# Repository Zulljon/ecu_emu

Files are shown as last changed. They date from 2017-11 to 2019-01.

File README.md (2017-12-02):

# ECU emulator v3.1a
PCB part of project (source codes unavailable!)

## Scheme
scheme_svg
scheme_pdf

## PCB
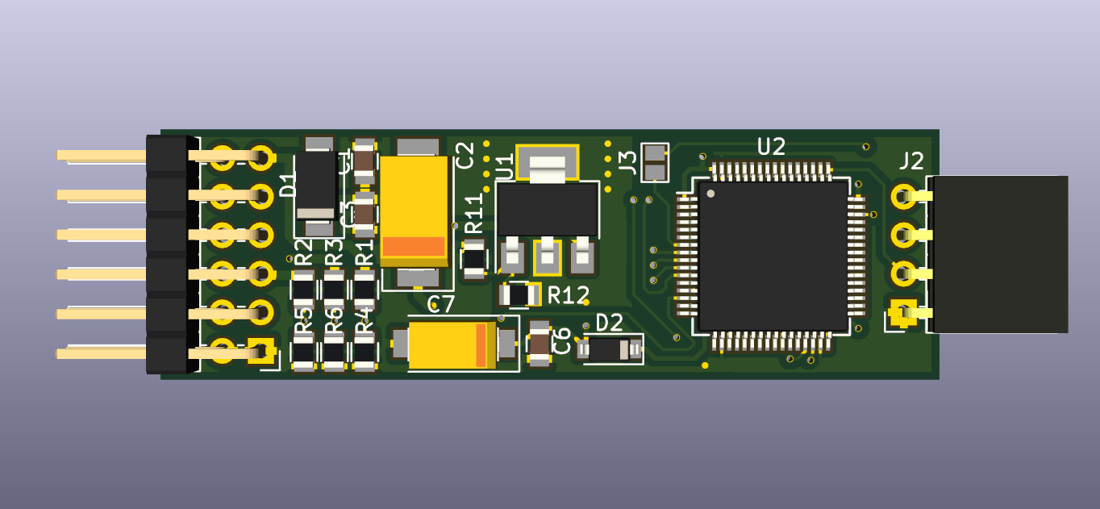
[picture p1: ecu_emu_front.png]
FRONT_side_png

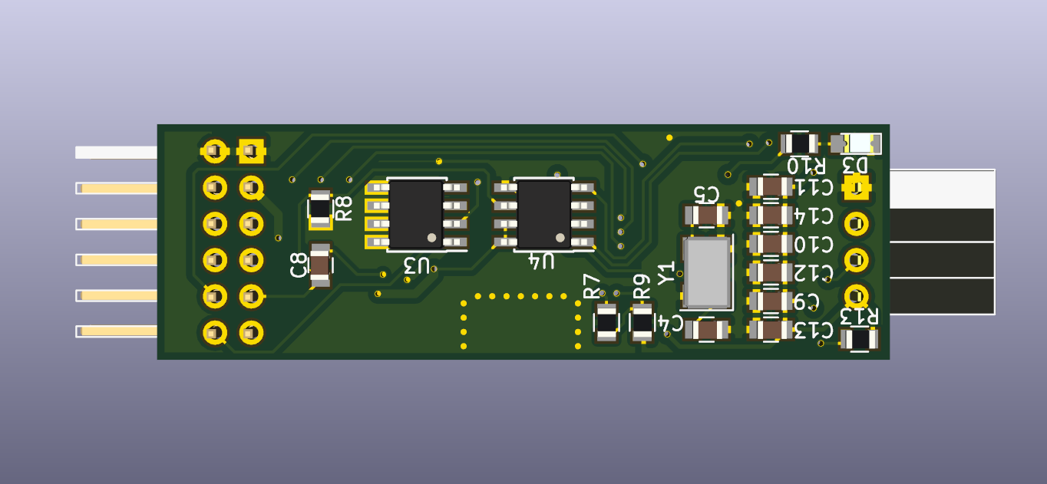
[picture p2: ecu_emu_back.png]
BACK_side_png

### With FreeCAD PCB mod
pcb_mod
### With FreeCAD KiCAD StepUp mod
stepup_mod

## Tools
- KiCAD v4.0.7
- FreeCAD v0.15

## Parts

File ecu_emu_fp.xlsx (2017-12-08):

Source: | d:/zulljon/KiCAD/ecu_emu/ecu_emu.sch
Date: | 2017-12-07 18:20
Tool: | Eeschema 4.0.7
Generator: | C:/Program Files/KiCad/bin/scripting/plugins/bom_csv_grouped_by_value_with_fp.py
Component Count: | 34
Ref | Qnty | Value | Cmp name | Footprint | Description | Vendor
C1, | 1 | 10nF | C | Capacitors_SMD:C_0805 | Unpolarized capacitor
C2, | 1 | 220uF x 30V | CP | Capacitors_Tantalum_SMD:CP_Tantalum_Case-X_EIA-7343-43_Wave | Polarised capacitor
C3, C10, C11, C12, C13, C14, | 6 | 100nF | C | Capacitors_SMD:C_0805 | Unpolarized capacitor
C4, C5, | 2 | 16pF | C | Capacitors_SMD:C_0805 | Unpolarized capacitor
C6, | 1 | 10uF | C | Capacitors_SMD:C_0805 | Unpolarized capacitor
C7, | 1 | 47uF x 16V | CP | Capacitors_Tantalum_SMD:CP_Tantalum_Case-C_EIA-6032-28_Wave | Polarised capacitor
C8, | 1 | 1nF | C | Capacitors_SMD:C_0805 | Unpolarized capacitor
C9, | 1 | 4.7uF | C | Capacitors_SMD:C_0805 | Unpolarized capacitor
D1, | 1 | SS22A-SS210A-Galaxy | D_Schottky | Diodes_SMD:D_SMA | Schottky diode
D2, | 1 | PMLL4148L.115 | D | Diodes_SMD:D_SC-80 | Diode
D3, | 1 | LED | LED | LEDs:LED_0805 | LED generic
J1, | 1 | Conn_02x06_Odd_Even | Conn_02x06_Odd_Even | Pin_Headers:Pin_Header_Angled_2x06_Pitch2.54mm | Generic connector, double row, 02x06, odd/even pin numbering scheme (row 1 odd numbers, row 2 even numbers)
J2, | 1 | Conn_01x04_Male | Conn_01x04_Male | Socket_Strips:Socket_Strip_Angled_1x04_Pitch2.54mm | Generic connector, single row, 01x04
R1, R2, R3, | 3 | 9k | R | Resistors_SMD:R_0805 | Resistor
R4, R5, R6, | 3 | 2k2 | R | Resistors_SMD:R_0805 | Resistor
R7, R9, R8, R10, | 4 | 1k | R | Resistors_SMD:R_0805 | Resistor
U1, | 1 | LD1117S33TR_SOT223 | LD1117S33TR_SOT223 | TO_SOT_Packages_SMD:SOT-223-3_TabPin2 | 1A Low Dropout regulator, positive, 1.5V fixed output, SOT-223
U2, | 1 | STM32F105RBTx | STM32F105RBTx | Housings_QFP:LQFP-64_10x10mm_Pitch0.5mm | Core: ARM Cortex-M3 Package: LQFP64 Flash: 64KB Ram: 64KB Frequency: 72MHz Voltage: 2..3.6V IO-pins: 51
U3, | 1 | BSP742R | BSP742R | Housings_SOIC:SOIC-8_3.9x4.9mm_Pitch1.27mm | Smart High-Side Power Switch 34V DSO-8 BSP742R, Intelligent Power Switch High Side Switch, 0.4A, -10 ??? 16V, 8-Pin, PG-DSO-8-24
U4, | 1 | E-L9637D | E-L9637D | Housings_SOIC:SOIC-8_3.9x4.9mm_Pitch1.27mm | Monolithic Bus Driver ISO 9141 Interface
Y1, | 1 | Crystal KX-9A | Crystal_GND24 | Crystals:Crystal_SMD_5032-4pin_5.0x3.2mm | Four pin crystal (GND on pins 2 and 4), e.g. in SMD package

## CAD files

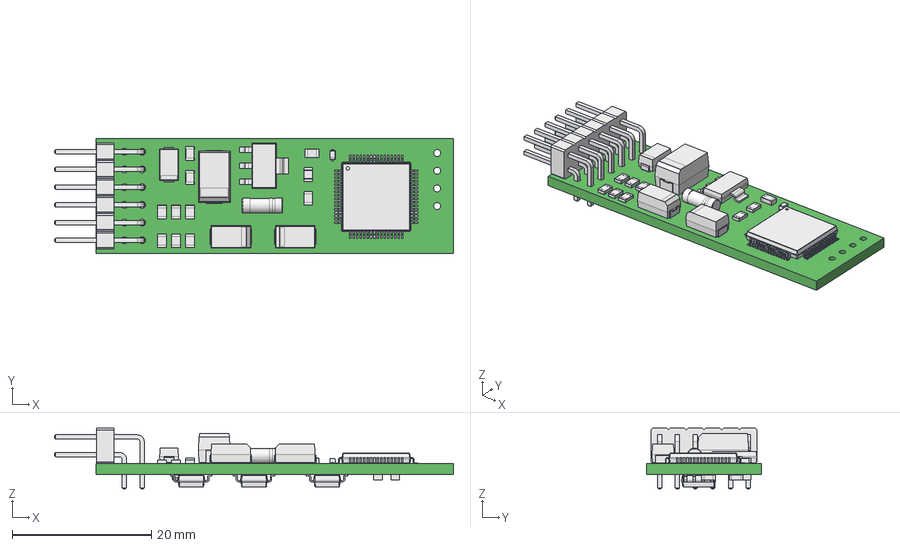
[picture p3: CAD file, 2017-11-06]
ecu_emu1.FCStd
57.3 x 16.5 x 8.72 mm
Pcb
C_0805_
C_0805_001
C_0805_002
C_0805_003
C_0805_004
C_0805_005
D_SMA_
D_SC_80_
Pin_Header_Angled_2x06_Pitch254mm_
SOIC-8_3.9x4.9mm_Pitch1.27mm_
R_0805_
R_0805_001
R_0805_002
R_0805_003
R_0805_004
R_0805_005
R_0805_006
R_0805_007
SOT_223_
LQFP-64_10x10mm_Pitch0.5mm_
SOIC-8_3.9x4.9mm_Pitch1.27mm_001
SOIC-8_3.9x4.9mm_Pitch1.27mm_002
CP_Tantalum_Case-X_EIA-7343-43_
CP_Tantalum_Case-C_EIA-6032-28_
CP_Tantalum_Case-C_EIA-6032-28_001
D_MELF_Standard_
R_0805_008

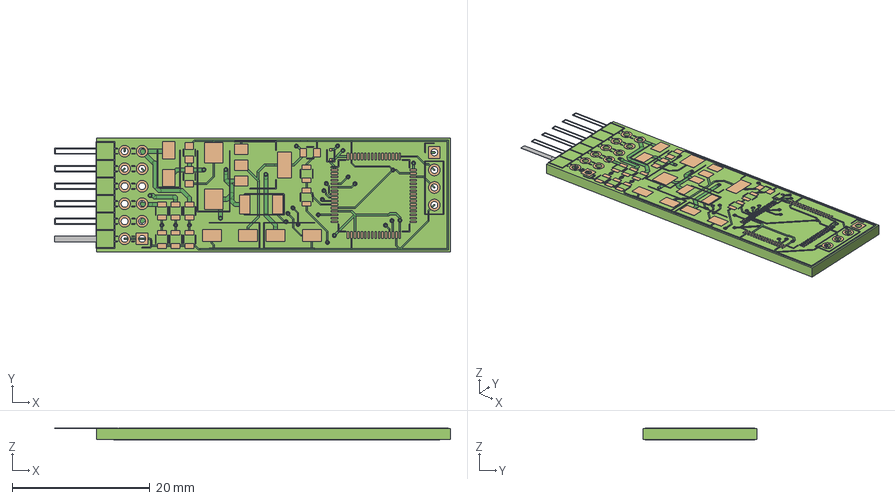
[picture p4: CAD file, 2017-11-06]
ecu_emu2.FCStd
57.4 x 16.5 x 1.67 mm
Board
F_Cu_0
bPad_107
tPad_108
B_Cu_31
B_SilkS_36
F_SilkS_37

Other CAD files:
ecu_emu1.stl
ecu_emu2.stl

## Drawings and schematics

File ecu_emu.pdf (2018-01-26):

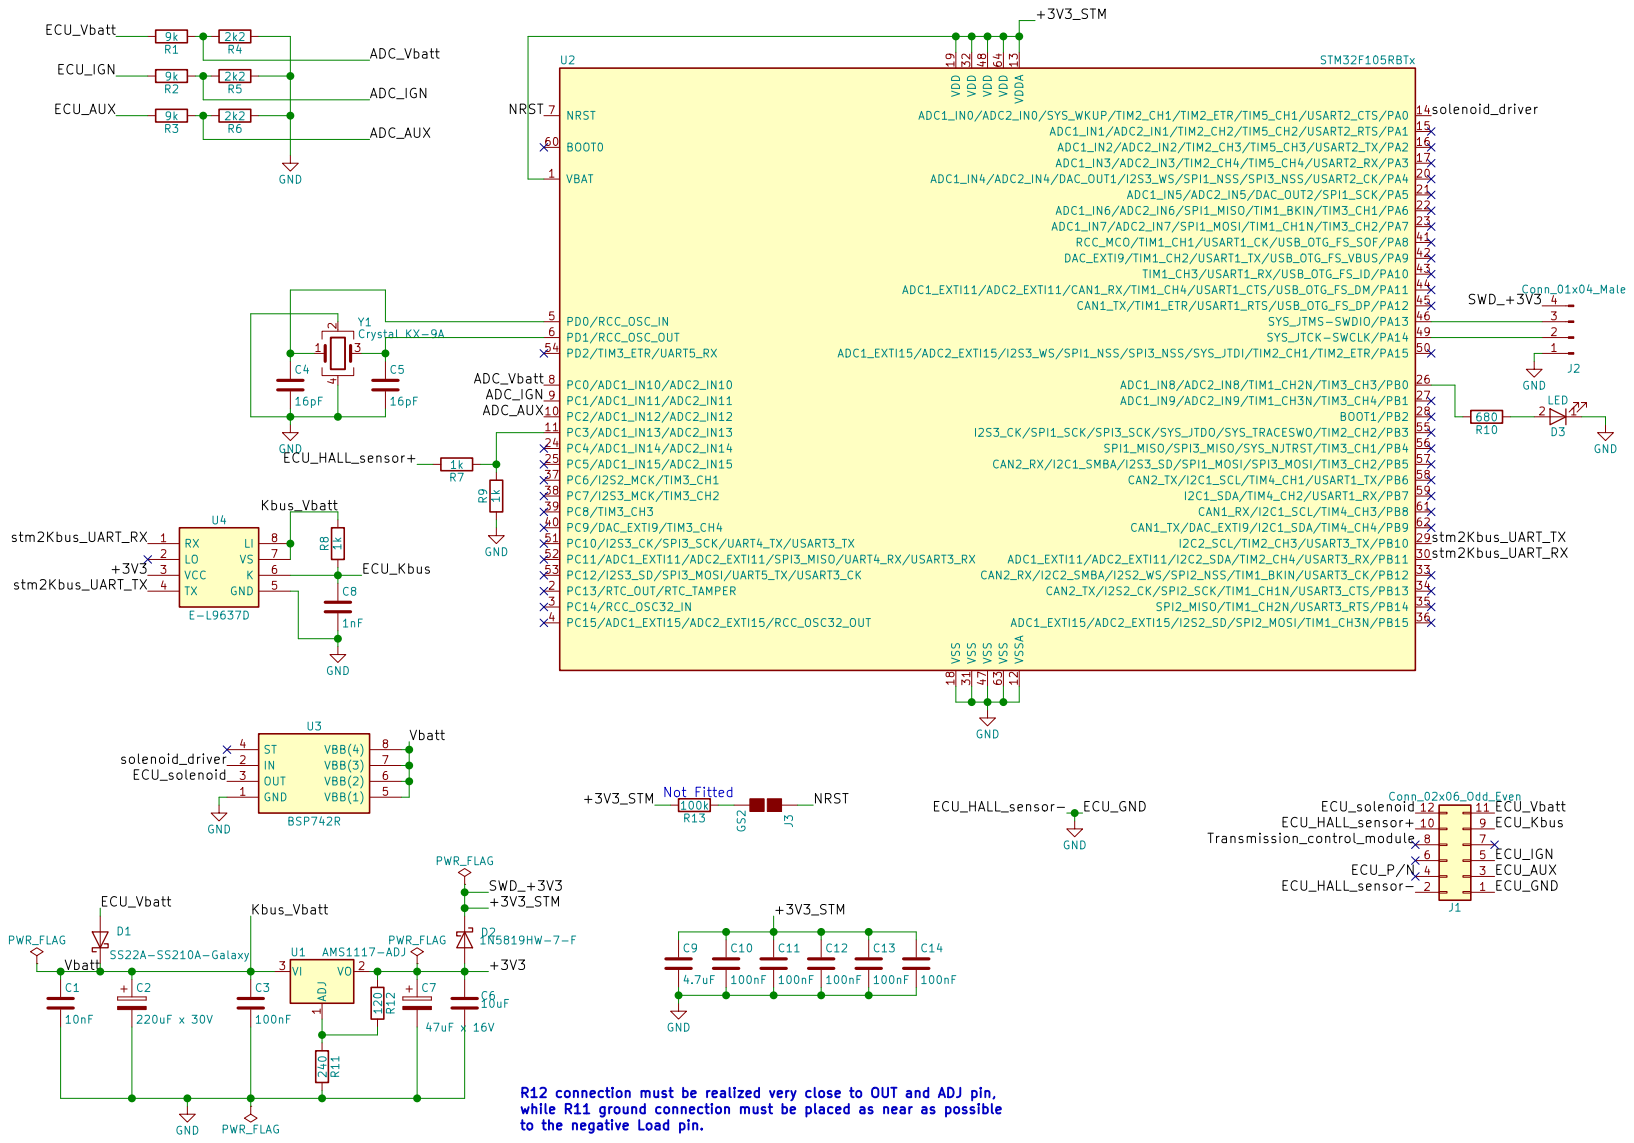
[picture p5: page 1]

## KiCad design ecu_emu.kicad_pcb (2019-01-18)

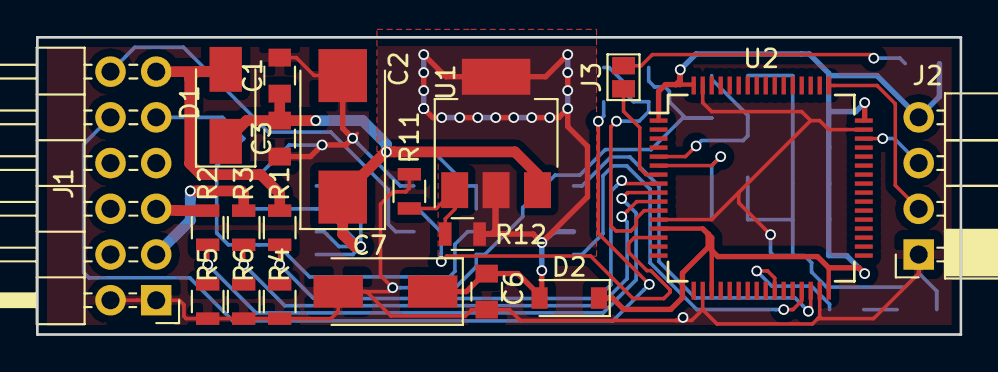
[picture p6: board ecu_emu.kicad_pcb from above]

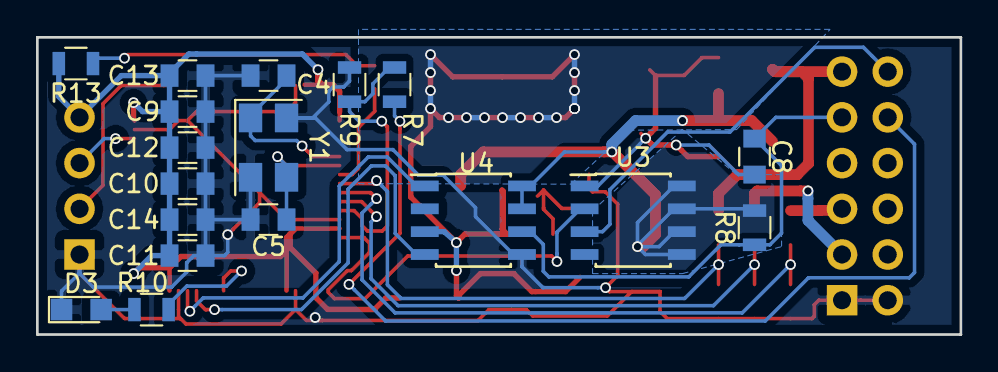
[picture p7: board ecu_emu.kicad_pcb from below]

Board: 2 copper layers, 51.3 x 16.5 mm, 38 parts (18 on the bottom side), 26 nets.

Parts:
C1: 10nF; C_0805
C2: 220uF x 30V; CP_Tantalum_Case-X_EIA-7343-43_Wave
C3, C10, C11, C12, C13, C14: 100nF; C_0805
C4, C5: 16pF; C_0805
C6: 10uF; C_0805
C7: 47uF x 16V; CP_Tantalum_Case-C_EIA-6032-28_Wave
C8: 1nF; C_0805
C9: 4.7uF; C_0805
D1: SS22A-SS210A-Galaxy; D_SMA
D2: 1N5819HW-7-F; D_SOD-123
D3: LED; LED_0805
J1: Conn_02x06_Odd_Even; Pin_Header_Angled_2x06_Pitch2.54mm
J2: Conn_01x04_Male; Socket_Strip_Angled_1x04_Pitch2.54mm
J3: GS2
R1, R2, R3: 9k; R_0805
R4, R5, R6: 2k2; R_0805
R7, R8, R9, R10: 1k; R_0805
R11: 240; R_0805
R12: 120; R_0805
R13: 100k; R_0805
U1: AMS1117-ADJ; SOT-223-3_TabPin2
U2: STM32F105RBTx; LQFP-64_10x10mm_Pitch0.5mm
U3: BSP742R; SOIC-8_3.9x4.9mm_Pitch1.27mm
U4: E-L9637D; SOIC-8_3.9x4.9mm_Pitch1.27mm
Y1: Crystal KX-9A; Crystal_SMD_5032-4pin_5.0x3.2mm

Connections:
/+3V3: C6.1, C7.1, D2.2, R12.1, U1.2, U4.3
/+3V3_STM: C9.1, C10.1, C11.1, C12.1, C13.1, C14.1, D2.1, J2.4, R13.2, U2.1, U2.13, U2.19, U2.32, U2.48, U2.64
/ADC_AUX: R3.1, R6.2, U2.10
/ADC_IGN: R2.1, R5.2, U2.9
/ADC_Vbatt: R1.1, R4.2, U2.8
/ECU_AUX: J1.3, R3.2
/ECU_HALL_sensor+: J1.10, R7.2
/ECU_IGN: J1.5, R2.2
/ECU_Kbus: C8.1, J1.9, R8.1, U4.6
/ECU_Vbatt: D1.2, J1.11, R1.2
/ECU_solenoid: J1.12, U3.3
/Kbus_Vbatt: C1.1, C2.1, C3.1, D1.1, R8.2, U1.3, U3.5, U3.6, U3.7, U3.8, U4.7, U4.8
/NRST: J3.1, U2.7
/solenoid_driver: U2.14, U3.2
/stm2Kbus_UART_RX: U2.30, U4.1
/stm2Kbus_UART_TX: U2.29, U4.4
GND: C1.2, C2.2, C3.2, C4.2, C5.2, C6.2, C7.2, C8.2, C9.2, C10.2, C11.2, C12.2, C13.2, C14.2, D3.1, J1.1, J1.2, J2.1, R4.1, R5.1, R6.1, R9.1, R11.2, U2.12, U2.18, U2.31, U2.47, U2.63, U3.1, U4.5, Y1.2, Y1.4
unnamed: C4.1, U2.5, Y1.1
unnamed: C5.1, U2.6, Y1.3
unnamed: D3.2, R10.1
unnamed: J2.2, U2.49
unnamed: J2.3, U2.46
unnamed: J3.2, R13.1
unnamed: R7.1, R9.2, U2.11
unnamed: R10.2, U2.26
unnamed: R11.1, R12.2, U1.1

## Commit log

2017-10-26 init local repo
    [ecu_emu.kicad_pcb, ecu_emu.sch]
2017-10-26 add README file, with svg graphics
    [ecu_emu.sch]
2017-11-03 1. solenoid rules with MOSFET and his driver 2. chane LIN to K-Bus cirquit 3. add shotky diod
    [ecu_emu.sch]
2017-11-04 add 3D wiev of pcb
    [ecu_emu.stl]
2017-11-05 add second 3d modele
    [ecu_emu2.stl]
2017-11-06 sch: add resistor to hall sensor input
    [ecu_emu.sch]
2017-11-06 add drawing of pcb
    [ecu_emu.kicad_pcb]
2017-11-06 add graphics to git readme file
    [ecu_emu.stl, ecu_emu1.FCStd, ecu_emu1.stl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]
2017-11-15 switch to my library https://github.com/Zulljon/zpkl.git
    [ecu_emu.kicad_pcb, ecu_emu.sch, ecu_emu1.FCStd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]
2017-12-02 scheme: change solenoid driver, add capasitors to stm power supply, fix crystal package
    [ecu_emu.kicad_pcb, ecu_emu.sch]
2017-12-02 pcb: swd conn to socket strip, applied sch changes from 059fb19
    [ecu_emu.kicad_pcb, ecu_emu.sch]
2017-12-04 pcb: add additional vias and zones to linear stabilazer on bottom side
    [ecu_emu.kicad_pcb]
2017-12-05 sch&pcb: add one LED and refresh readme image
    [ecu_emu.kicad_pcb, ecu_emu.sch]
2017-12-06 generate gerber files & add .sh to zip them
    [ecu_emu-B.Adhes.gbr, ecu_emu-B.CrtYd.gbr, ecu_emu-B.Cu.gbr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]
2017-12-06 zipped gerber files
2017-12-08 add descriptions for gerber files
2017-12-08 add BOM file
    [ecu_emu_fp.xlsx]
2018-01-26 more fixes 1. separate power on k-bus IC logic 2. D2 change to shottky diod 3. pull-up on stm RESET pin 4. change linier stabilizer to adjastable version, to make apropriate voltage on stm throw diod
    [ecu_emu-B.Adhes.gbr, ecu_emu-B.CrtYd.gbr, ecu_emu-B.Cu.gbr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]
2019-01-18 fix some, update gerbers
    [ecu_emu.kicad_pcb]
2019-01-18 fix chmod a-x
    [ecu_emu.sch, ecu_emu1.FCStd, ecu_emu1.stl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]
